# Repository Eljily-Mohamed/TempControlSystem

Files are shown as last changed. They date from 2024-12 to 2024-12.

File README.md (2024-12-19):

# Objectifs du Projet

Notre mission lors de ce projet d'Instrumentation et Puissance des Systèmes (IPS) a été de concevoir un système d'asservissement de température pour une résistance chauffante. L'objectif principal est de mesurer et réguler précisément la température à l'aide d'une thermistance et d'un capteur de courant.

## **Objectifs Détaillés**

À partir du cahier des charges, nous nous sommes répartis les différentes tâches. L'objectif final est de :

- Concevoir un système de mesure complet permettant de relever des données telles que la température et le courant consommé par la résistance.
- Réguler la température en ajustant la puissance appliquée à la résistance chauffante via un MOSFET, en fonction des mesures effectuées.
- La mise en œuvre d’un **capteur de courant ACS712** pour surveiller la puissance consommée par la résistance chauffante.  
- Analyser les résultats obtenus pour les comparer avec les prévisions théoriques issues de l'équation de la chaleur.
- Étudier l'influence de la convection forcée en utilisant un ventilateur pour améliorer la dissipation thermique.

## **Schéma Fonctionnel**

Pour atteindre nos objectifs, nous avons établi un schéma fonctionnel décrivant le fonctionnement global du système. Ce schéma comprend :

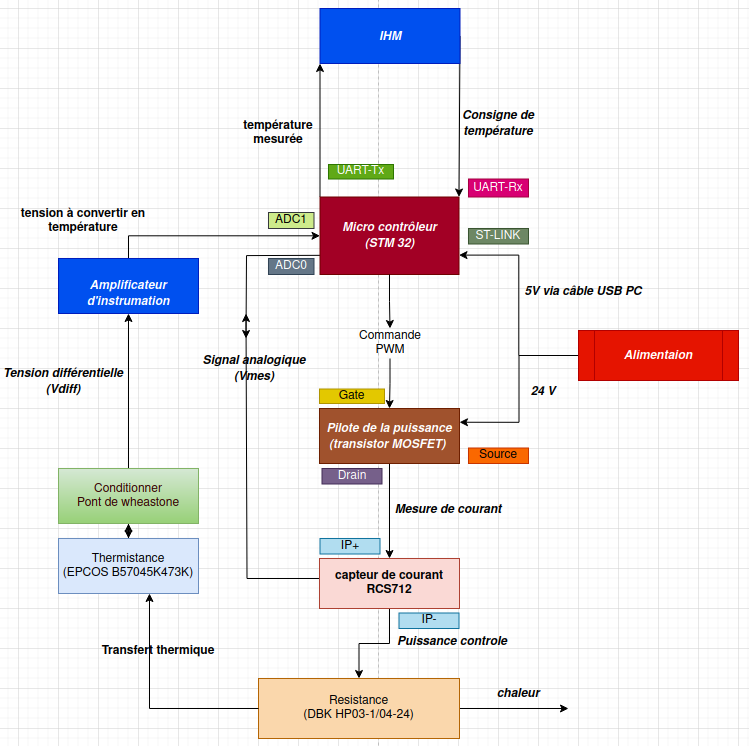
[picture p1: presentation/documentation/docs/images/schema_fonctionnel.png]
Schéma Fonctionnel


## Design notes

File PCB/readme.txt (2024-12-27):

🔧 Modifications nécessaires pour le PCB :

    Le PCB actuel n'est pas le design final. Il manque des connexions importantes pour le fonctionnement correct pour capteur courant.

    Alimentation :
        Ajoutez une alimentation commune pour le +5V nécessaire aux AOP.
        Il y a deux broches importantes : IP+ et IP-. Connectez :
            Le drain du MOSFET à IP+.
            IP- à la résistance chauffante.

    Choix des résistances pour le pont :
        Les valeurs des résistances doivent être proches de la résistance R0 de la thermistance.
        Dans le code C, une fonction calcule la résistance de la thermistance en fonction des résistances R1, R2, et R3, grâce à la loi du pont (vue en cours).
        Le pont est constitué de 4 résistances :
            Thermistance, R1, R2, et R3.

    Résistance pull-down :
        La résistance pull-down connectée au MOSFET doit être placée entre le drain et la gate.
        Vous pouvez souder cette résistance directement sans l'ajouter au PCB.
        Une valeur de 10 kΩ est bonne, mais pas obligatoire. Vous pouvez ajuster selon le besoin.

    Transistor et alimentation :
        Alimentez le transistor avec une tension de 24V.
        Pour le transistor utilisé ici :
            La broche source est au centre.
            Les autres sont drain et gate (voir le PCB).

    Configuration de la gate (PWM) :
        Vous pouvez modifier la broche de la gate pour qu’elle soit connectée à D13.
        Si ce n’est pas le cas, après réception du PCB, vous pouvez réaliser un pontage avec un câble reliant D13 à la broche utilisée.
        Dans le code, j’utilise D13 pour générer un signal PWM.

👉 Si vous avez besoin d’autres précisions ou d’un choix spécifique, faites-moi signe !

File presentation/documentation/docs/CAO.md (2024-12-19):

# Carte Électronique
## **Conception et Tests**

Après avoir testé individuellement chaque composant de la carte, nous avons constaté que les valeurs fournies par la thermistance sont faibles et perturbées.

Pour résoudre ce problème et garantir une précision optimale, nous utilisons un amplificateur différentiel AD623, qui ajuste, amplifie et stabilise le signal avant son envoi vers la carte STM32 pour traitement.

Dans un premier temps, le câblage a été réalisé sur une **plaque Labdec** pour vérifier la fonctionnalité de chaque composant. Une fois les tests validés, nous avons procédé à la **conception assistée par ordinateur (CAO)** du circuit électronique en utilisant un logiciel dédié, ce qui a permis de finaliser la carte PCB présentée en image ci-dessous.

## **Schéma PCB**
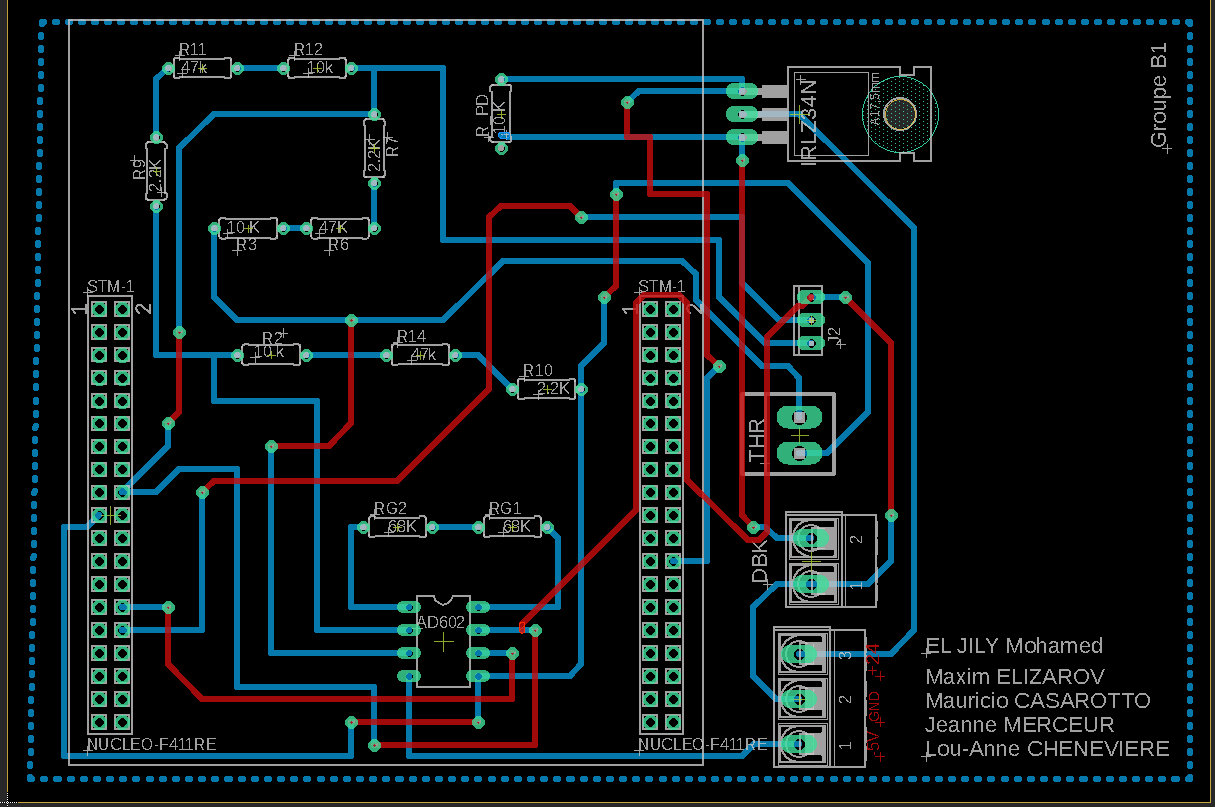
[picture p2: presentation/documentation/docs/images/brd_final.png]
brd final
 

## Description du Circuit

La carte électronique exploite plusieurs composants essentiels pour la réalisation du projet d’asservissement de température :

### 1. **Pont de Wheatstone**  
Le circuit utilise une configuration en **pont de Wheatstone** pour mesurer les faibles variations de résistance de la thermistance. La sortie du pont fournit une tension proportionnelle à la variation de température, exprimée par la relation suivante :  

Vm = (ΔR / R) * Ve

Cependant, la tension obtenue est faible et sensible aux perturbations.

### 2. **Amplification du Signal**  
Afin d'améliorer la précision des mesures et réduire l'impact du bruit observé lors des tests initiaux, nous utilisons un **amplificateur différentiel AD623**. Cet amplificateur permet d’ajuster, stabiliser et amplifier le signal provenant du pont de Wheatstone avant son envoi vers la carte **STM32** pour traitement numérique.

### 3. **Connectivité et Contrôle**  
- **STM32** : La carte STM32 joue un rôle central dans l'acquisition et le traitement des données.  
- **Connectique** : La carte intègre une connectivité facilitant l’interaction avec d’autres composants, tels que le ventilateur pour la convection forcée.

## Réalisation Finale

L’image présentée illustre la carte PCB finale, incluant :  
- Les connexions avec les jauges de déformation et la thermistance,  
- Le pont de Wheatstone pour la mesure des résistances,  
- L’amplificateur **AD623** pour la stabilisation et l’amplification du signal,  
- Les ports de connexion **STM32** pour le traitement numérique et les actions correctives.

Cette carte représente une solution optimisée pour le projet d’asservissement de température, permettant d'obtenir des résultats précis tout en minimisant le bruit et les perturbations.

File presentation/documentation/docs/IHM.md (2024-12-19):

# IHM

L'interface graphique ci-dessous permet de superviser et de contrôler le système de régulation de température basé sur un élément chauffant. Elle offre une vue d'ensemble sur les mesures de température, la puissance appliquée et les paramètres de régulation en temps réel.

## Fonctionnalités principales :

- **Point de Consigne de Température** : Permet de définir la température cible en °C.
- **Mesures affichées** :
  - **Tension (V)** : La tension mesurée.
  - **Duty Cycle (%)** : Le pourcentage du signal PWM utilisé pour contrôler la puissance.
  - **Courant (A)** : Le courant mesuré.
- **Graphiques** :
  - **Température au fil du temps** : Suivi de la température du système.
  - **Variation de puissance** : Suivi de la puissance envoyée à l'élément chauffant.

## Contrôle de l'acquisition :
Un bouton **"Démarrer l'acquisition"** permet de commencer la collecte et l'affichage des données en temps réel.

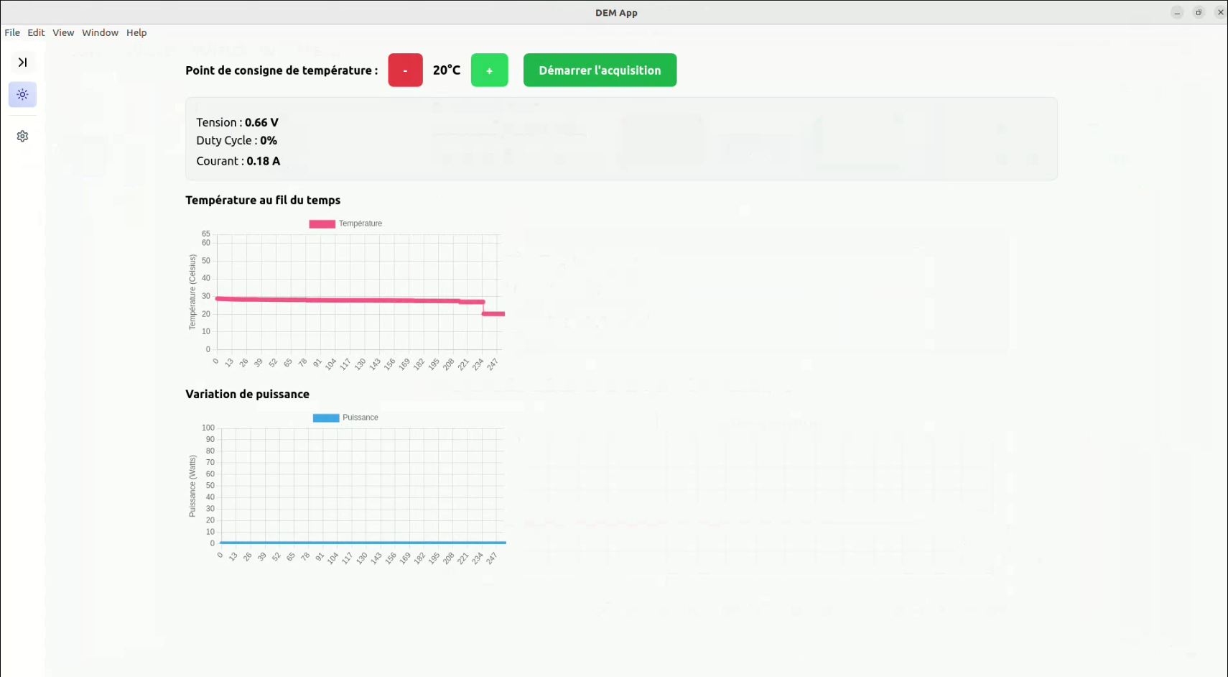
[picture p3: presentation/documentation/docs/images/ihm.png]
IHM


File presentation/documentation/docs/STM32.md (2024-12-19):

# STM32

Avant de commencer les tâches spécifiques à notre projet, il est essentiel de configurer les broches, récupérer les tensions via l'ADC et utiliser les minuteries. Ces bases sont indispensables pour les tâches à venir dans le cadre du module IPS.

## Tâche 1 : Programmation d'une tâche périodique (1 seconde)

Nous devons configurer des minuteries pour créer des tâches périodiques sur la carte STM32.

**Objectifs :**
- **Configurer un timer** pour générer des interruptions périodiques.
- **Vérifier les périodes** avec un oscilloscope.

**Pourquoi c'est important pour le projet :**  
Cela permettra de gérer les actions périodiques et synchroniser le traitement des données.

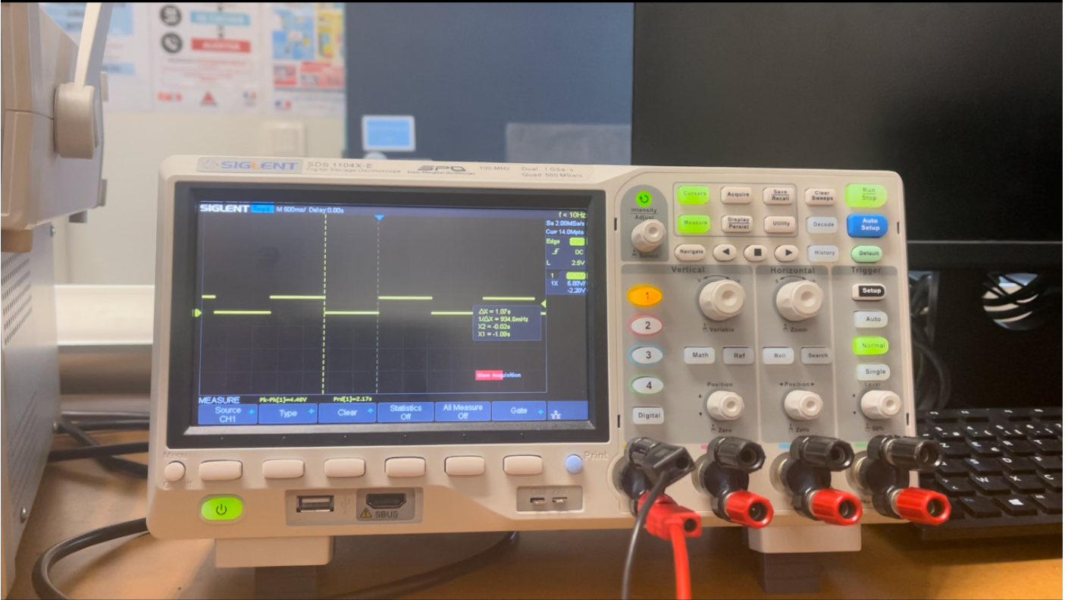
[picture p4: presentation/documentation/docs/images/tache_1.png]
Tâche 1


## Tâche 2 : Acquisition d'une donnée analogique via l'ADC

Nous utiliserons l'ADC pour lire une valeur analogique, puis la convertir en une tension numérique.

**Objectifs :**
- **Configurer l'ADC** pour lire la donnée analogique.
- **Convertir et afficher** la tension correspondante.

**Pourquoi c'est important pour le projet :**  
Cela permet d'acquérir des données analogiques provenant des capteurs.

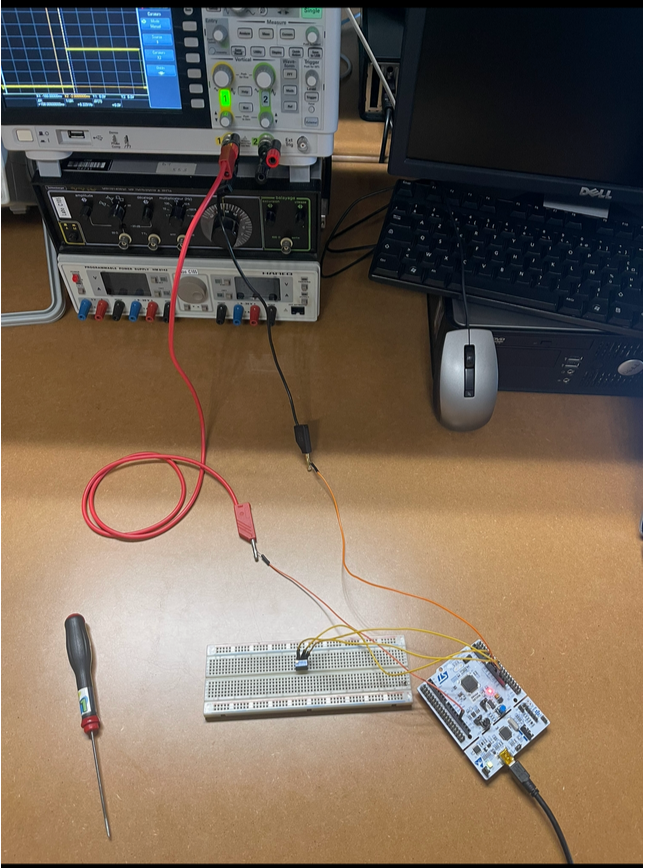
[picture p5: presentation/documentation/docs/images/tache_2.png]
Tâche 2


## Tâche 3 : Envoi des données vers le PC via UART (USB)

Nous enverrons les données acquises de la STM32 vers un PC via UART.

**Objectifs :**
- **Configurer UART** pour envoyer les données vers le PC.
- **Vérifier la transmission** avec un terminal comme PuTTY.

**Pourquoi c'est important pour le projet :**  
Cela permet de visualiser et analyser les données collectées.

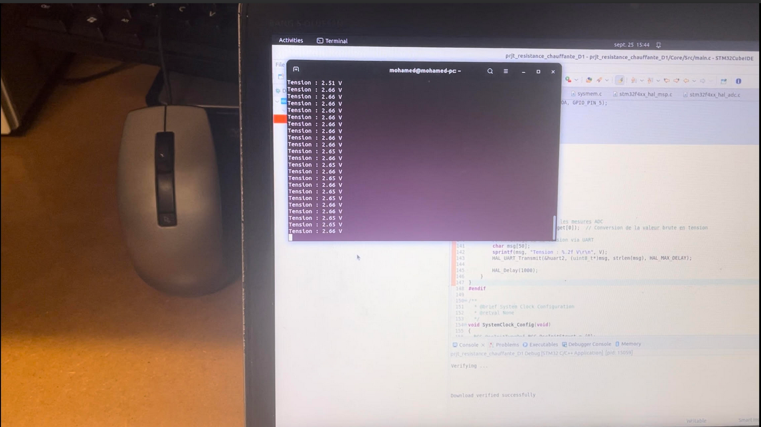
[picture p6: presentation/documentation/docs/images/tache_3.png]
Tâche 3


# Processus Expérimental du Projet STM32

Une fois les tâches de configuration de la carte STM32 terminées, nous démarrons le processus expérimental global du projet.

## 1. Câblage du Système Global

Après avoir finalisé les tâches de configuration sur la carte STM32, nous passons à l'étape suivante qui consiste à câbler l'ensemble du système.

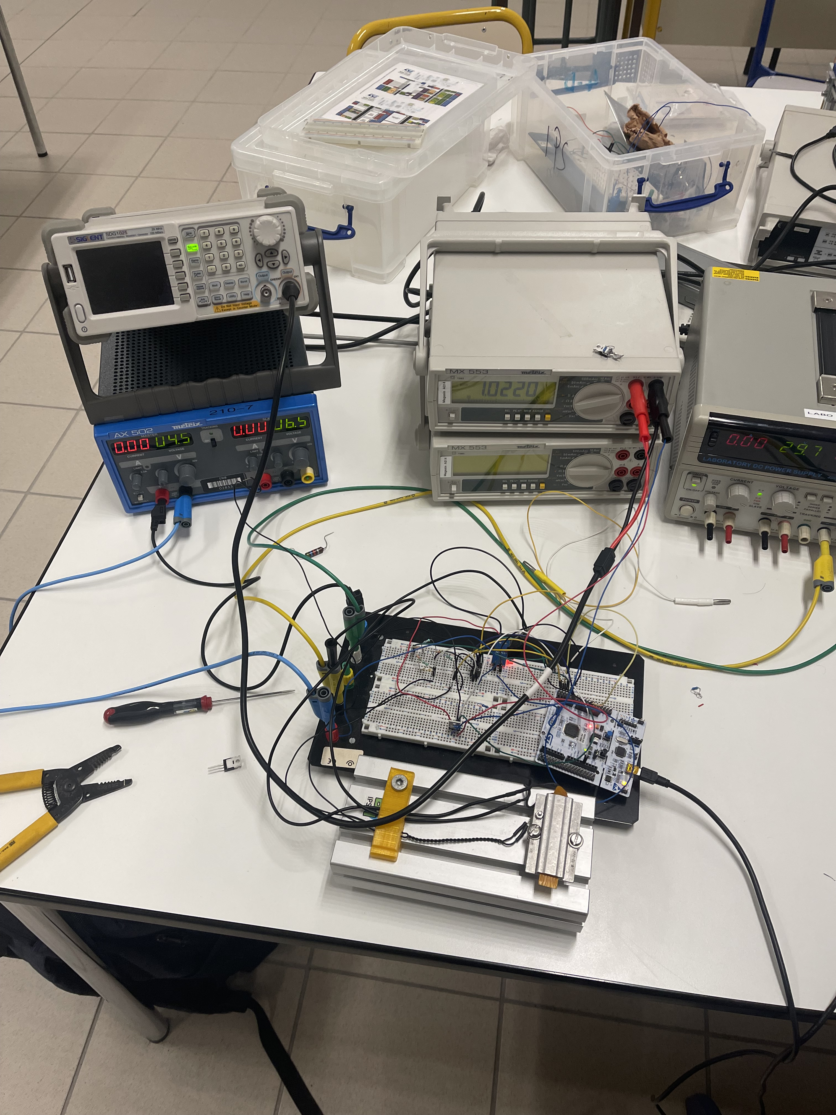
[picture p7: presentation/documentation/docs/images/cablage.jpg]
Câblage du système


### Étapes :
- **Câblage de la broche PA0** : Cette broche est utilisée pour récupérer la tension en sortie de l'AOP.
- **Vérification du signal** : À l'aide d'un multimètre, nous vérifions que la tension récupérée sur PA0 correspond à la tension attendue sortie de l'AOP.

## 2. Ajout d'une Broche pour la Récupération de la Sortie du Capteur de Courant

Une fois le câblage vérifié, nous ajoutons une autre broche, **PA1**, pour récupérer la sortie du capteur de courant. Cette étape est cruciale pour l'acquisition des données nécessaires à l'asservissement du système.

- **PA1** : Récupère la sortie du capteur de courant.

## 3. Mise en Place de la Tâche Périodique pour la Récupération des Données

Pour récupérer les données de manière régulière, nous configurons un timer afin de lancer la mesure périodiquement.

- **Timer périodique** : Permet de récupérer les mesures des capteurs à intervalles réguliers pour le traitement ultérieur.

## 4. Traitement des Données pour l'Asservissement

Une fois les données récupérées, nous passons à leur traitement pour calculer la température et déterminer le courant, afin de procéder à l'asservissement du système.

- **Calcul de la température** : À partir des données récupérées, la température est calculée.
- **Calcul du courant** : La mesure du courant est utilisée pour ajuster l'asservissement.

## 5. Contrôle du Signal PWM

Le traitement des données permet de déterminer le **duty cycle** du signal PWM, qui sera ensuite envoyé pour réguler la température et le courant dans l'élément chauffant.

- **PWM** : En fonction des calculs, un signal PWM est généré pour contrôler l'élément chauffant en fonction de la température et du courant mesurés.

## 6. Phase 3 : Récupération de la Consigne via USART

Dans cette phase, nous ajoutons la capacité de recevoir une consigne de température via la communication USART. Cette consigne permettra d'ajuster le comportement du système en fonction des demandes externes.

### Étapes :
- **Récupération de la consigne via USART** : Le système reçoit la consigne de température via un terminal ou une autre source, en utilisant la communication USART.
- **Modification de la consigne dans l'asservissement** : La consigne reçue via USART est utilisée pour ajuster la température cible, et donc le calcul du PWM.

## 7. Ajustement du PWM en fonction de la Consigne

Une fois la consigne reçue, le système adapte le calcul du signal PWM pour réguler la puissance envoyée à l'élément chauffant et atteindre la température cible spécifiée par la consigne.

- **Contrôle dynamique de la température** : La consigne via USART permet un contrôle dynamique et à distance de la température de l'élément chauffant, en ajustant le signal PWM en conséquence.

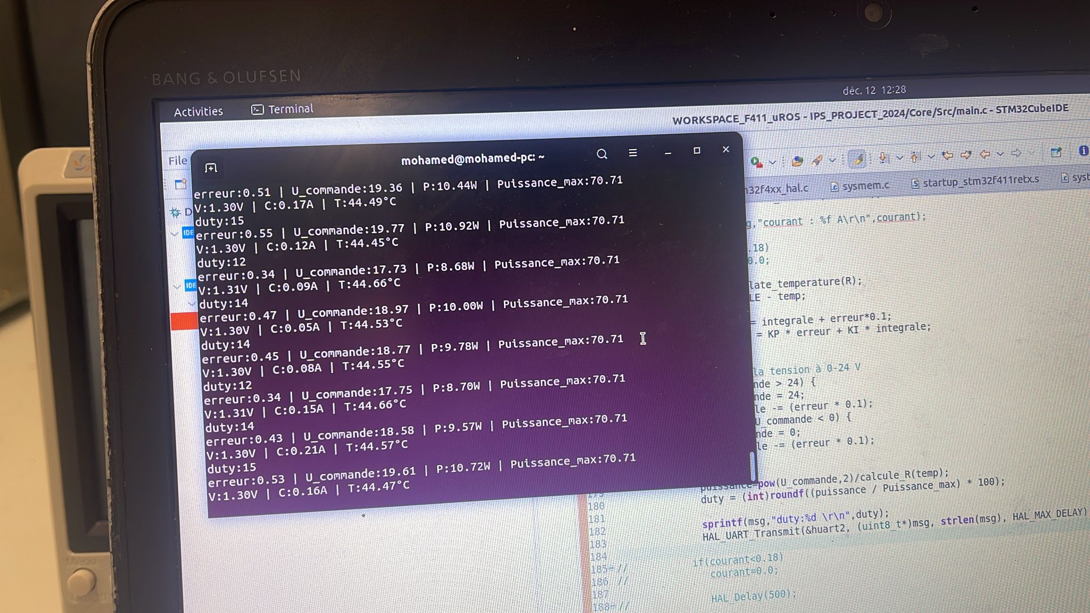
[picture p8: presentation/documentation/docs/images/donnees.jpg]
Données récupérées


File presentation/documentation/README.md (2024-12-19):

# Documentation du Projet avec MkDocs

Ce projet utilise **MkDocs** pour créer et héberger une documentation structurée.

## Prérequis

Assurez-vous d'avoir installé **Python** (>=3.6) et **pip** (le gestionnaire de paquets Python).

2. Installez les dépendances nécessaires :

   ```bash
   pip install -r requirements.txt
   ```

---

## Lancer la documentation en local

Pour visualiser votre documentation en local, exécutez la commande suivante :

```bash
mkdocs serve
```

Cela démarre un serveur local. Ouvrez votre navigateur et accédez à :

```
http://127.0.0.1:8000/
```

Les modifications apportées aux fichiers seront automatiquement rechargées.

## Lien vers notre site web
https://docs-ips.onrender.com/

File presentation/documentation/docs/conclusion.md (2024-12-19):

# Conclusion

## Comparaison expérimentale et finale

Nous avons étudié le chauffage et le refroidissement du système, d'abord de manière théorique, puis expérimentalement, afin de calibrer notre code STM32 et de tester le système final.
Nous avons constaté que les conditions extérieures, telles que la température ambiante, influencent significativement les mesures, entraînant des variations d’un jour à l’autre.
Cependant, en analysant le système dans différentes conditions, nous avons développé une solution plus fiable et modulable.

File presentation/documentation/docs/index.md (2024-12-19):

# Page d'accueil du projet

Bienvenue sur la documentation de notre projet, réalisé par des étudiants de l'École Nationale d'Ingénieurs de Brest (ENIB). Ce projet a pour objectif de concevoir un système d'instrumentation permettant de mesurer et de réguler précisément la température d'une résistance chauffante à l'aide d'une thermistance et d'un capteur de courant.

## **Régulation de Température d’une Résistance Chauffante par Thermistance**

Dans ce projet, nous avons développé un système qui repose sur :  
- L’utilisation d’une **résistance chauffante** et d’une **thermistance** pour contrôler et mesurer la température en temps réel.  

## **Composants clés utilisés**

### **Résistance chauffante : DBK HP03-1/04-24**  

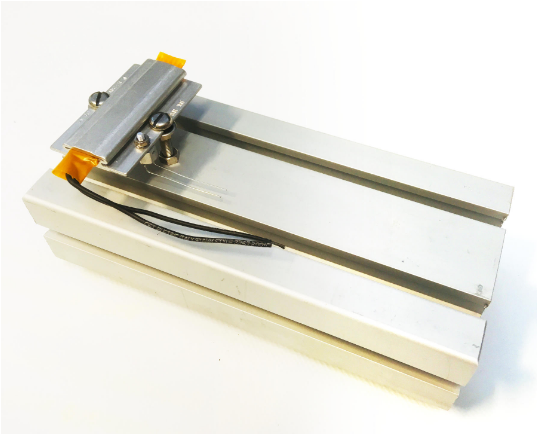
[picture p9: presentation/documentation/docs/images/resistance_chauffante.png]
Résistance chauffante
  

La **DBK HP03-1/04-24** est une résistance chauffante compacte et fiable, idéale pour des expériences de contrôle de température nécessitant une précision élevée.  

### **Thermistance : EPCOS B57045K473K**  

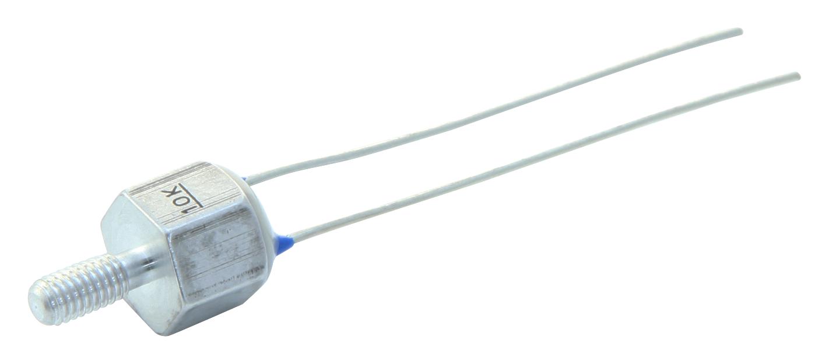
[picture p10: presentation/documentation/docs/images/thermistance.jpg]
Thermistance
  

La **thermistance EPCOS B57045K473K** offre une sensibilité accrue pour mesurer avec précision les variations de température. Elle est idéale pour un système d'asservissement nécessitant une mesure en temps réel.  

### **Capteur de courant : ACS712**  

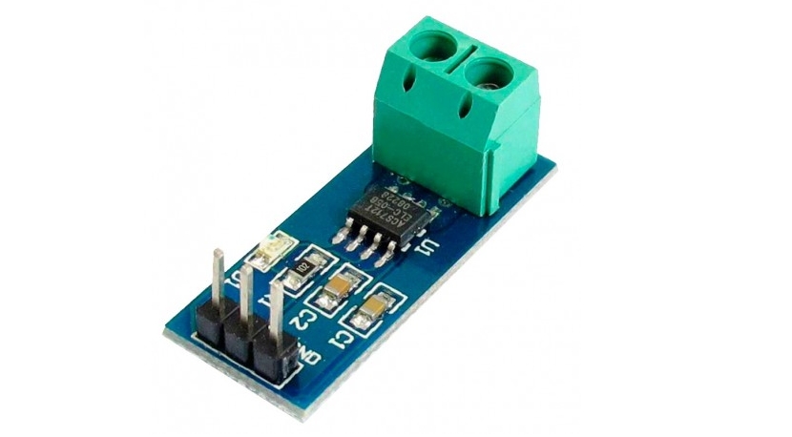
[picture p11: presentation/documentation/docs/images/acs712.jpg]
Capteur de courant ACS712
  

Le **capteur de courant ACS712** permet de mesurer avec précision le courant consommé par la résistance chauffante. Ces mesures sont essentielles pour analyser la relation entre la puissance dissipée et la variation de température du système.

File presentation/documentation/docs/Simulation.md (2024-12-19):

# Simulation théorique

## **Introduction**  
L'étude repose sur **l'équation de la chaleur** avec les paramètres :  
**m** : masse | **Cp** : capacité thermique | **hc** : convection | **S** : surface | **T(t)** : température | **P(t)** : puissance | **Ta** : température ambiante.

La température est calculée via l'équation NTC :  
Equation Chaleur

Des tests de **chauffage** et de **refroidissement** sont effectués en mesurant la résistance de la thermistance à chaque instant pour en calculer la température avec l'équation suivante :  
Equation Refroidissement  
Pendant le chauffage, V = 12 V a été utilisé.

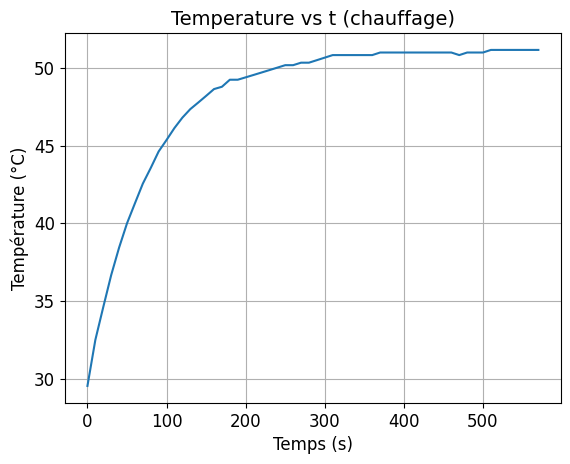
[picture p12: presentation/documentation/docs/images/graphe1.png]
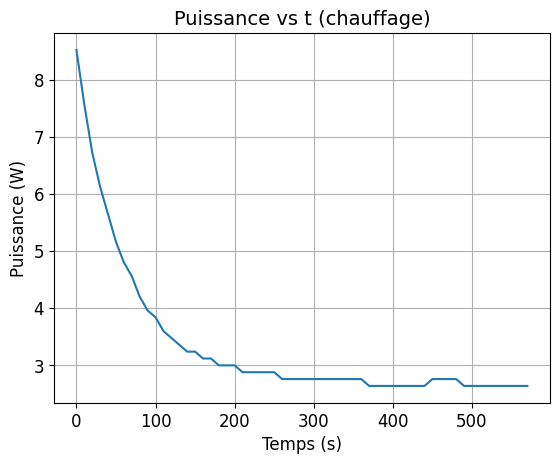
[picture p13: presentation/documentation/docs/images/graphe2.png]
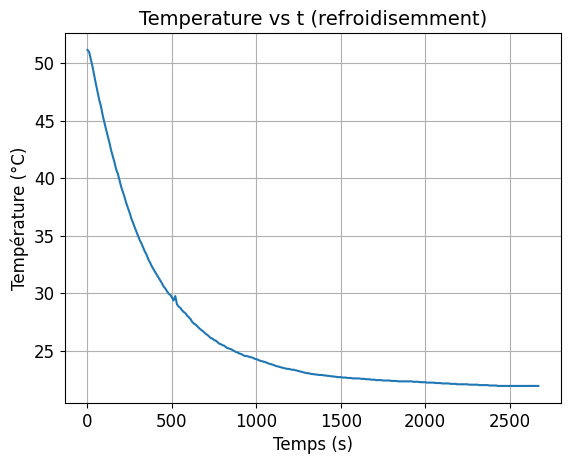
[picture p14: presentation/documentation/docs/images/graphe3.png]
Graphique 3
|  |  |  |
|---|---|---|
| Graphique 1 | Graphique 2 | Graphique 3 |

## **Estimation des paramètres**  
Nous avons utilisé l'équation de refroidissement, avec l'équation différentielle linéaire à coefficients constants, pour calculer les paramètres **m.Cp** et **hc.S**. Nous les regroupons en **a = m.Cp** et **b = hc.S** pour simplifier l'analyse.

L’équation simplifiée est :  
Equation simplifiée  
Sa solution est :  
Equation solution

Le facteur **a/b** représente la constante de temps **τ**, et avec **T(τ) = 0,63 Tfin**, nous obtenons **τ = 533.47s**.  

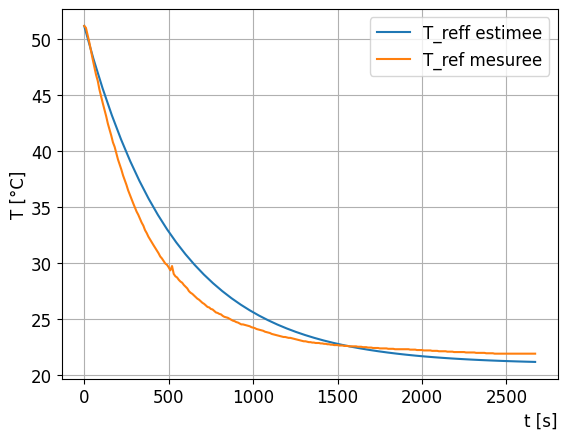
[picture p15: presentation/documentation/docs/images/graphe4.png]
Puissance


Pendant le chauffage, la température tend vers 50°C, donc **δT/δt = 0**, et nous trouvons que **a = 46.67Ws/K**. Cette équation permet de modéliser la variation de température pour une puissance d'entrée fixe de 14 W et la variation de la résistance en fonction de la température.

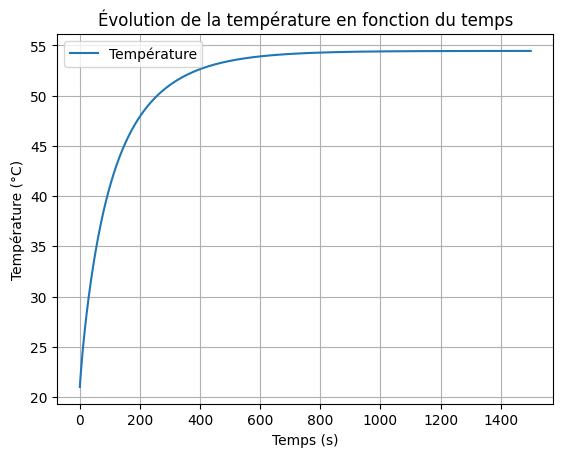
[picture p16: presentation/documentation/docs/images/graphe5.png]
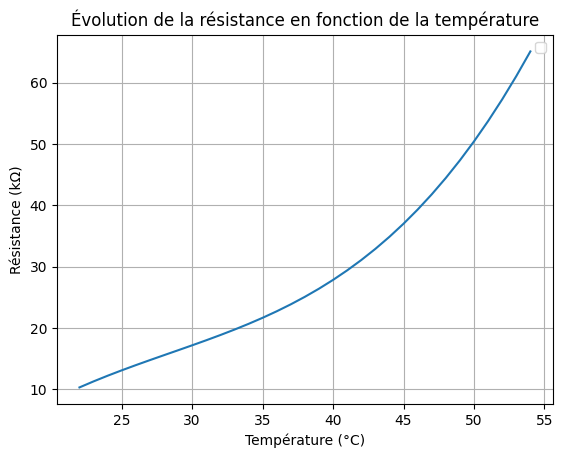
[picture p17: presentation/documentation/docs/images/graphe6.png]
|  |  |
|---|---|
| Graphique 1 | Graphique 2 |

## **Contrôle PID**  
Une fois les paramètres obtenus, les valeurs de gain ont commencé à être testées pour effectuer un contrôle PID, obtenant finalement KP= 8.1785, KI = 0.14733 et KD = 0 (Nous avons confirmé l'obtention d'une bonne réponse sans contrôle dérivé). Le contrôle a été modélisé à partir de ces valeurs pour différentes températures de consigne.

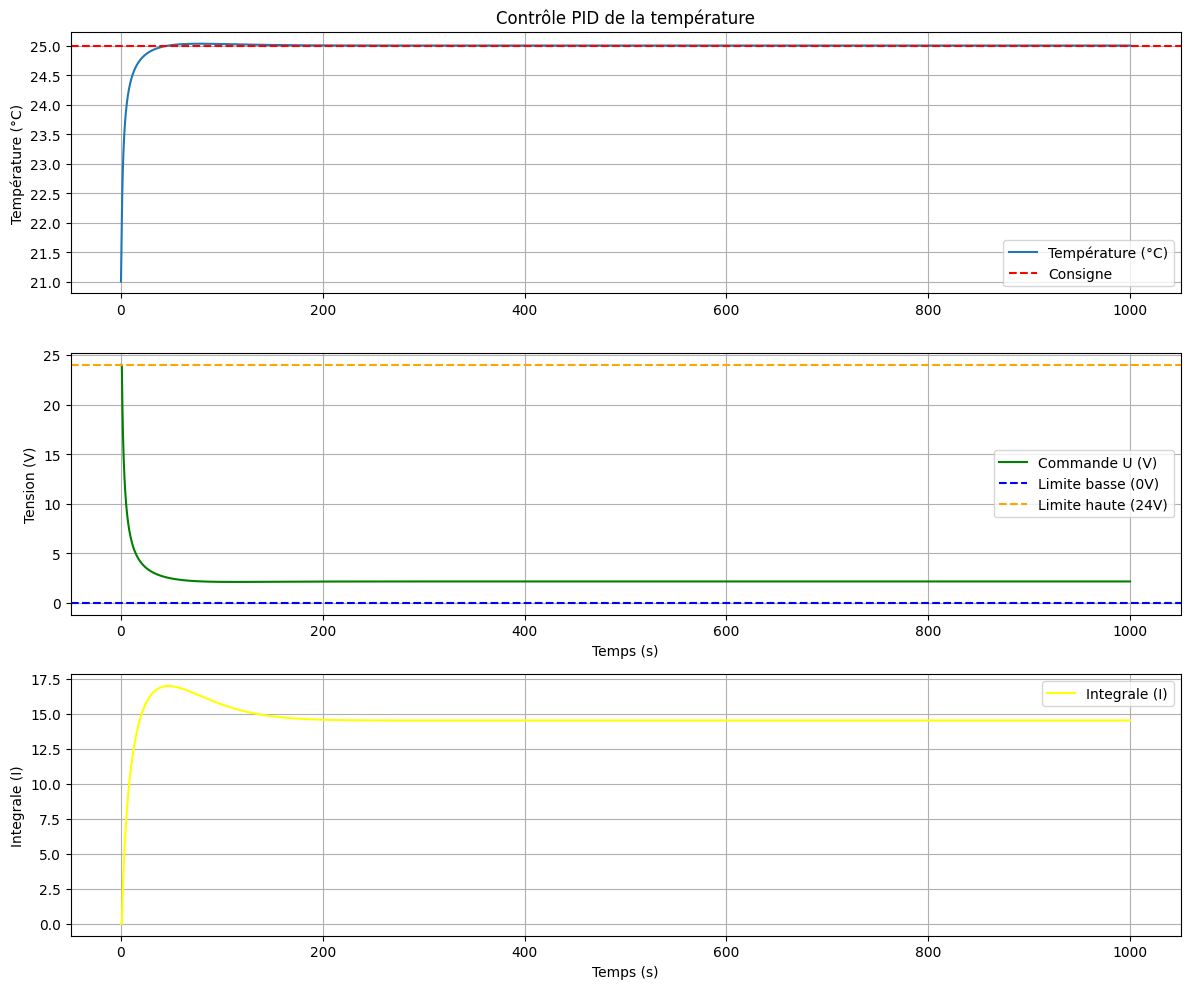
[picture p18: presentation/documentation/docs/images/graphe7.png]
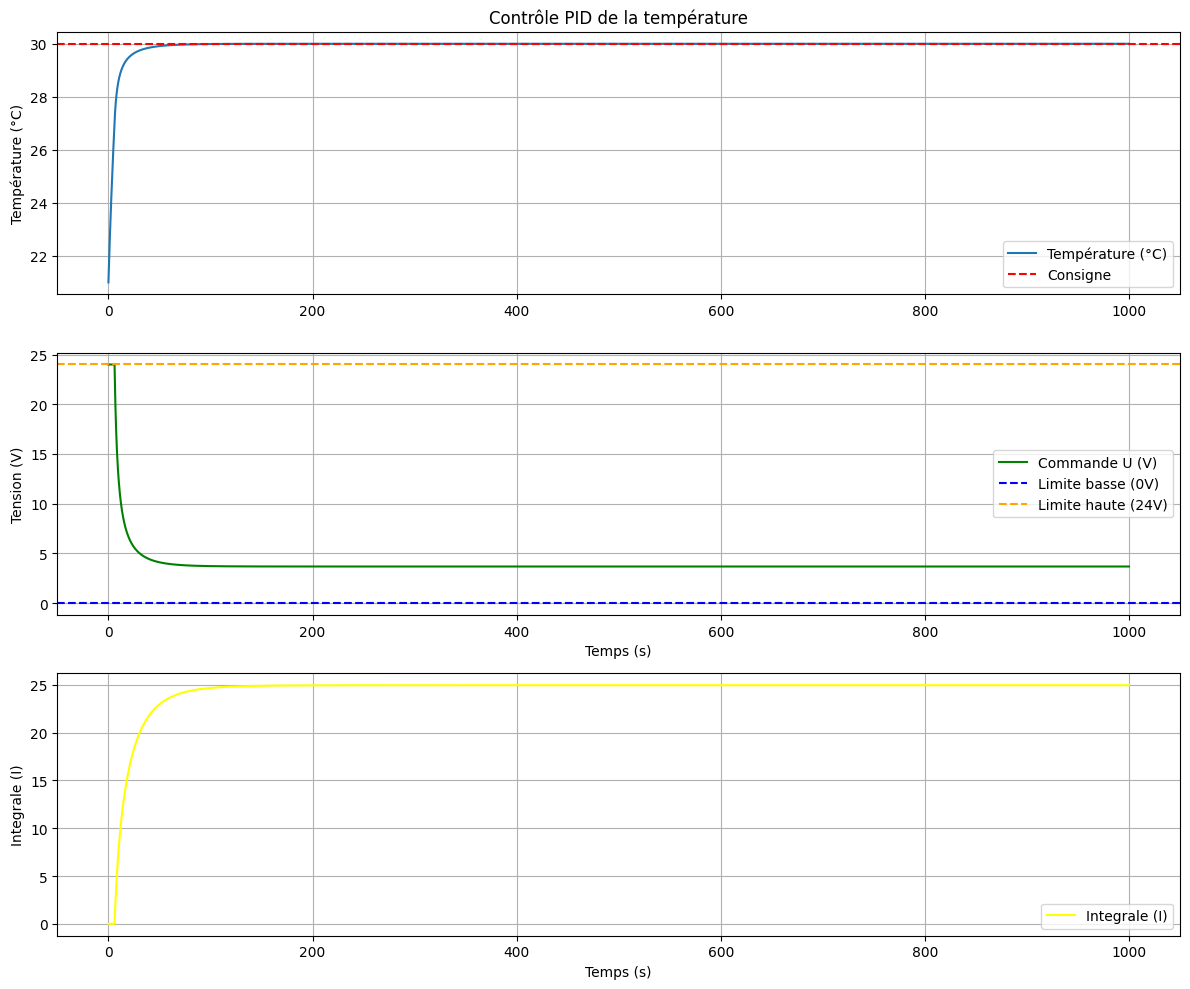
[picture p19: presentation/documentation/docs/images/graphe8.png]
|  |  |
|---|---|
| Graphique 1 | Graphique 2 |

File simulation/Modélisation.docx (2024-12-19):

Intro

Notre système est basé sur l'équation de la chaleur :

m.C_p .(dT(t))/(dt)+ h_c .S.T(t)=P(t)+ h_c .S.T_a (t)

- m : masse de la plaque chauffante
- Cp : capacité thermique spécifique
- hc : coefficient de transfert de chaleur par convection
- S : surface de confinement des pertes de chaleur
- T(t) : température en fonction du temps
- P(t) : puissance d'entrée en fonction du temps
- Ta : température ambiante

Ensuite, nous effectuons des tests de chauffage et de refroidissement, en mesurant à chaque instant la résistance de la thermistance pour en calculer la température grâce à l'équation T(r)= 1/(1/(T_0)+1/β.ln(r/(R_0))) , étant β constante bêta utilisée dans les équations de thermistance NTC, T0 et R0 valeurs de références (Pendant le chauffage, V = 12 V a été utilisé)


Estimation des paramètres

Nous avons utilisé l'équation de refroidissement pour calculer les paramètres, car nous travaillons ainsi avec une équation différentielle linéaire à coefficients constants car il n'y a pas de terme de puissance. Nous regroupons également les coefficients inconnus, m.Cp et hc.S, pour avoir deux inconnues, a = m.Cp et b = hc.S, au lieu de 4. L’équation résultante est donc a.(dT(t))/(dt)+ b.T(t)=b.T_a (t) , et sa solution est T(t)=(T_(max) -T_a ).e^(-(b.t)/a) +T_a , étant Tmax la température maximale atteinte pendant le chauffage.

Le facteur a/b est la constante de temps τ, et en développant l'expression précédente on arrive à τ= t/(log⁡((T_(max) -T_a)/(T-T_a)))

Sachant que T(τ) = 0,63.Tfin et en observant les valeurs de la courbe de refroidissement, τ = 533.47s a été déterminé


Lors du chauffage, la température tend vers 50°C, donc δT/δt= 0, alors a.δT/δt +b.(T-Ta)=Pe, en prenant la limite δT → 0, on obtient b=(P_e)/(T-T_a) = 0.0875W/K et on peut calculer a = τ*b = 46.67Ws/K.

Nous utilisons cette équation pour modéliser la variation de température pour une puissance d'entrée fixe de 14 W, ainsi que la variation de la résistance de la plaque en fonction de la température.


Une fois les paramètres obtenus, les valeurs de gain ont commencé à être testées pour effectuer un contrôle PID, obtenant finalement KP= 8.1785, KI = 0.14733 et KD = 0 (Nous avons confirmé l'obtention d'une bonne réponse sans contrôle dérivé). Le contrôle a été modélisé à partir de ces valeurs pour différentes températures de consigne.

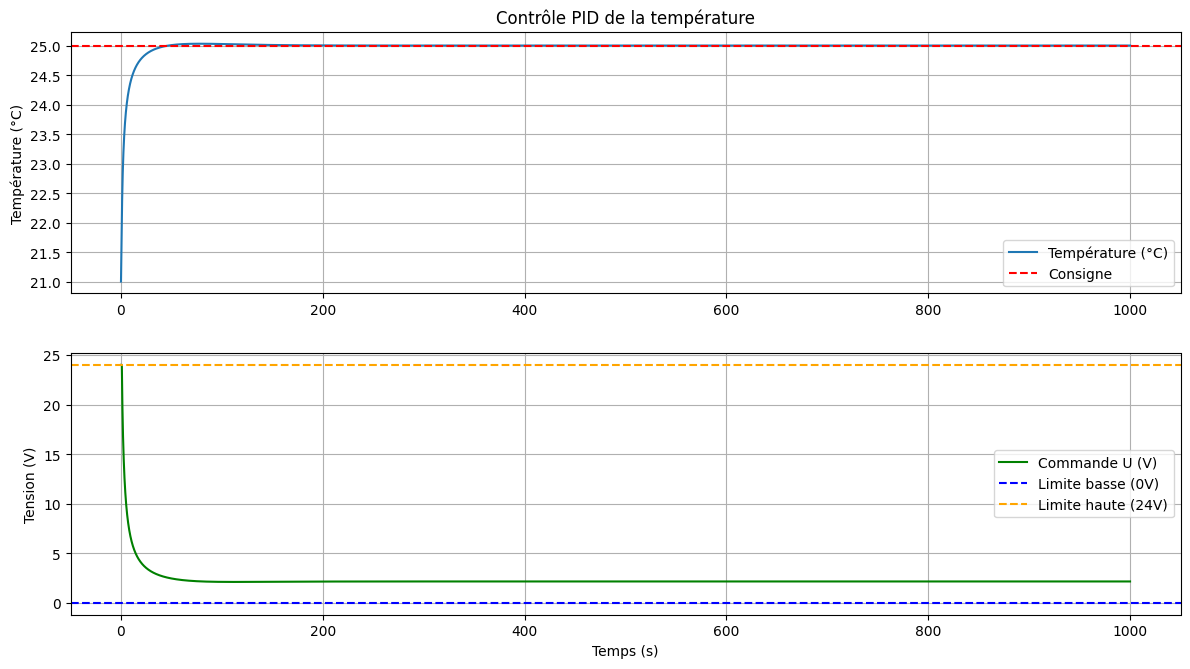
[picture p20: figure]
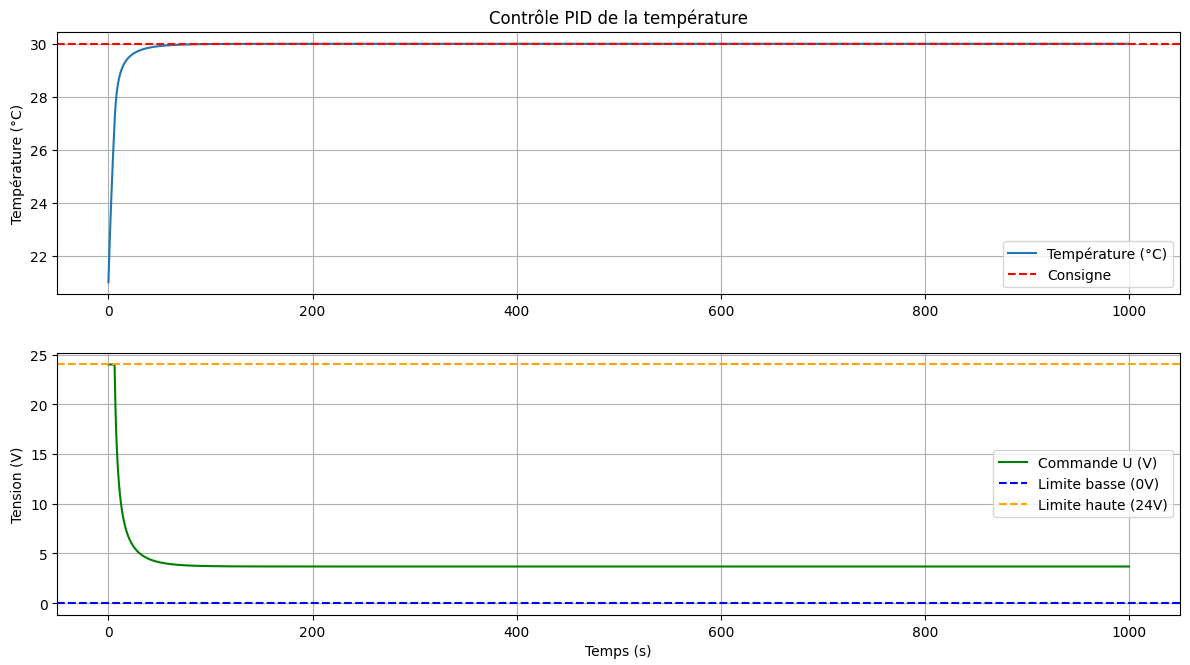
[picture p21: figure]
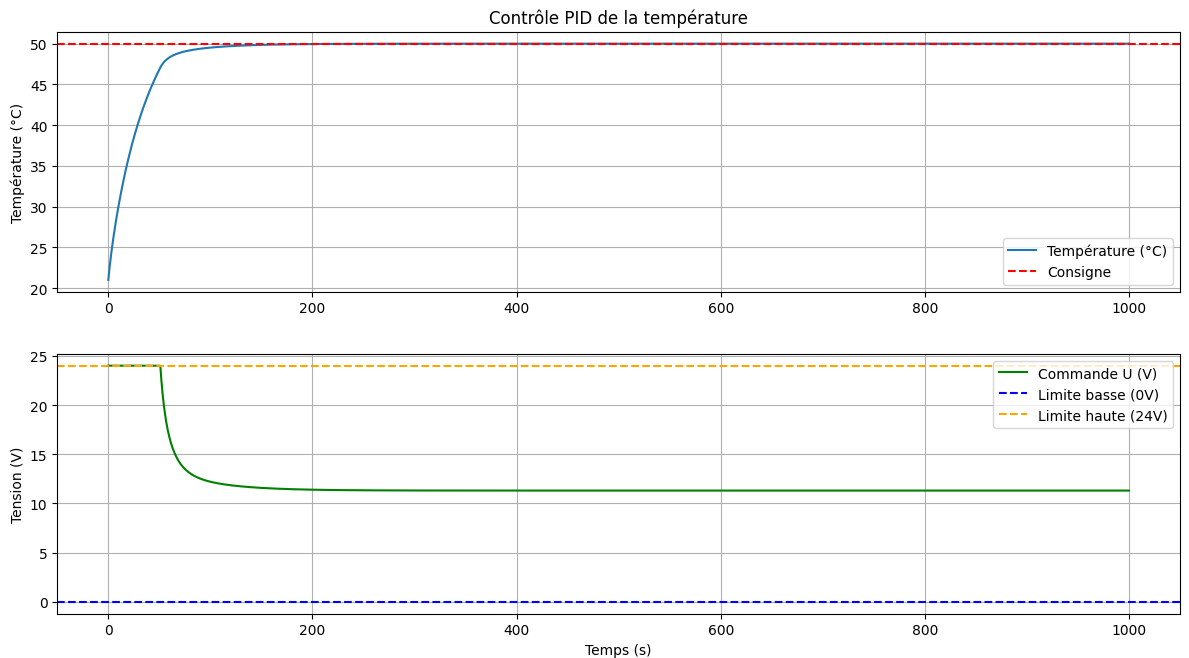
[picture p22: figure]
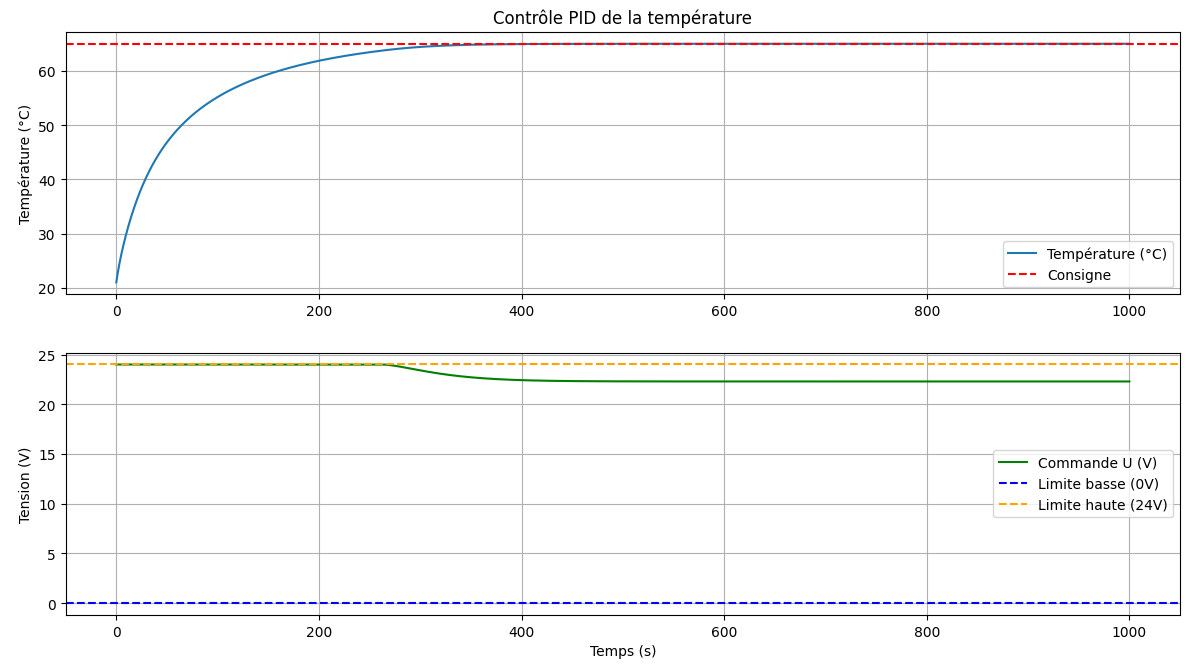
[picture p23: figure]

Nous vérifions que la température maximale réalisable avec la puissance utilisée est

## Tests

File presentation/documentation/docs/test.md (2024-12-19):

# Résultats et Analyse

Voici une démo de notre projet. La vidéo montre deux périodes : la période de refroidissement et la période de chauffage.

---

### Vidéo de démonstration

[Télécharger la vidéo ici](/videos/demo.mp4)

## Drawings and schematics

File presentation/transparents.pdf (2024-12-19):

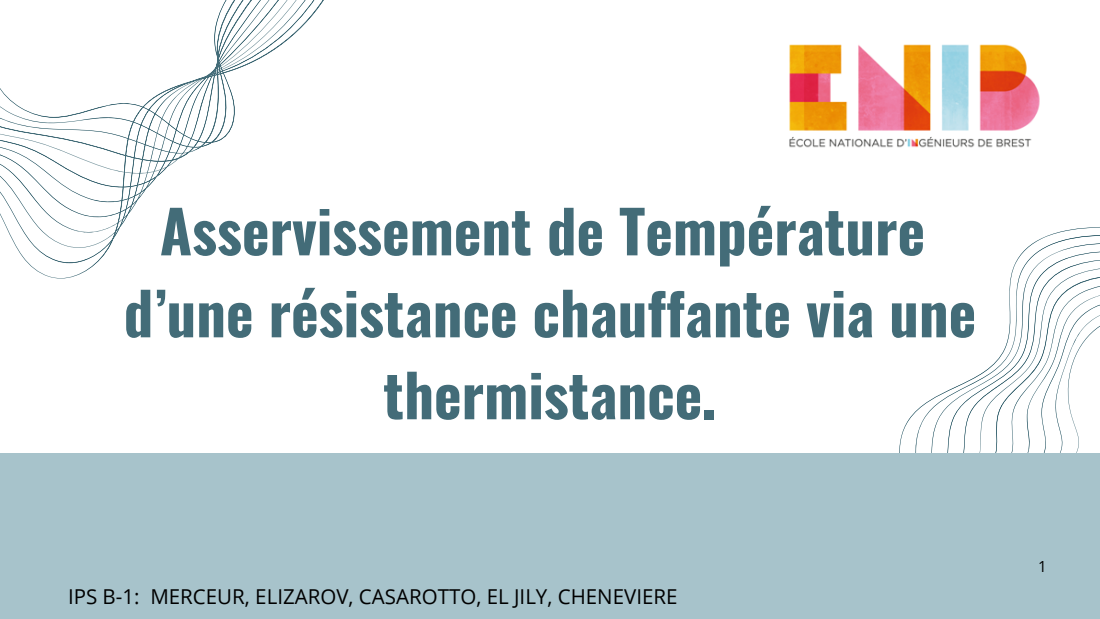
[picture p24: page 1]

Asservissement de Température
d’une résistance chauffante via une
thermistance.

IPS B-1: MERCEUR, ELIZAROV, CASAROTTO, EL JILY, CHENEVIERE

### CONTENT

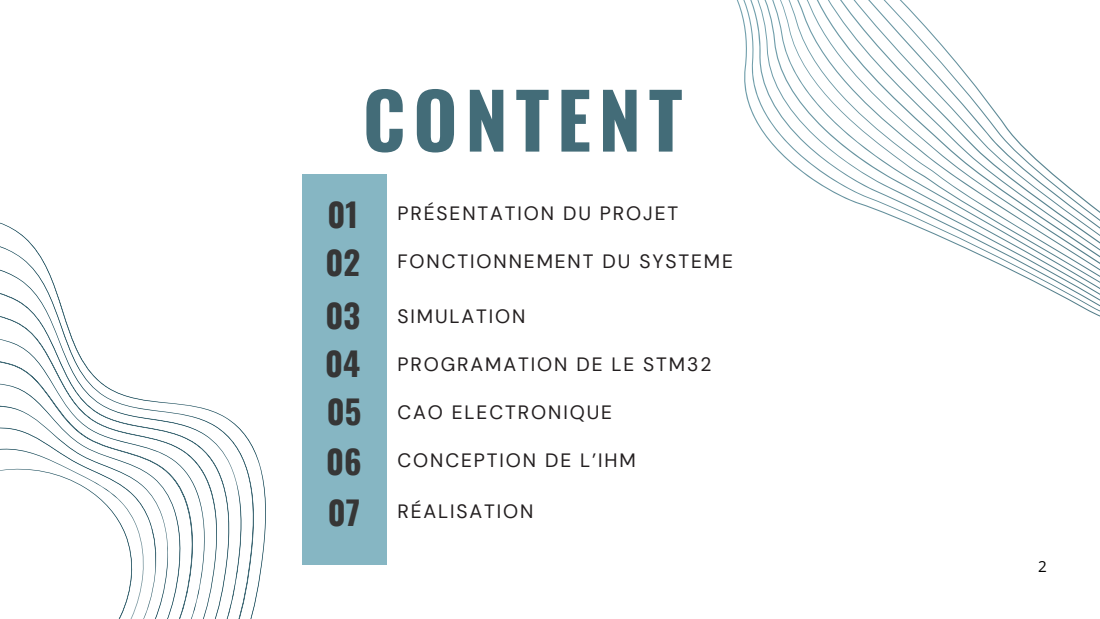
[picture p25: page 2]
PRÉSENTATION DU PROJET; SIMULATION; CAO ELECTRONIQUE; RÉALISATION

FONCTIONNEMENT DU SYSTEME

PROGRAMATION DE LE STM32

CONCEPTION DE L’IHM

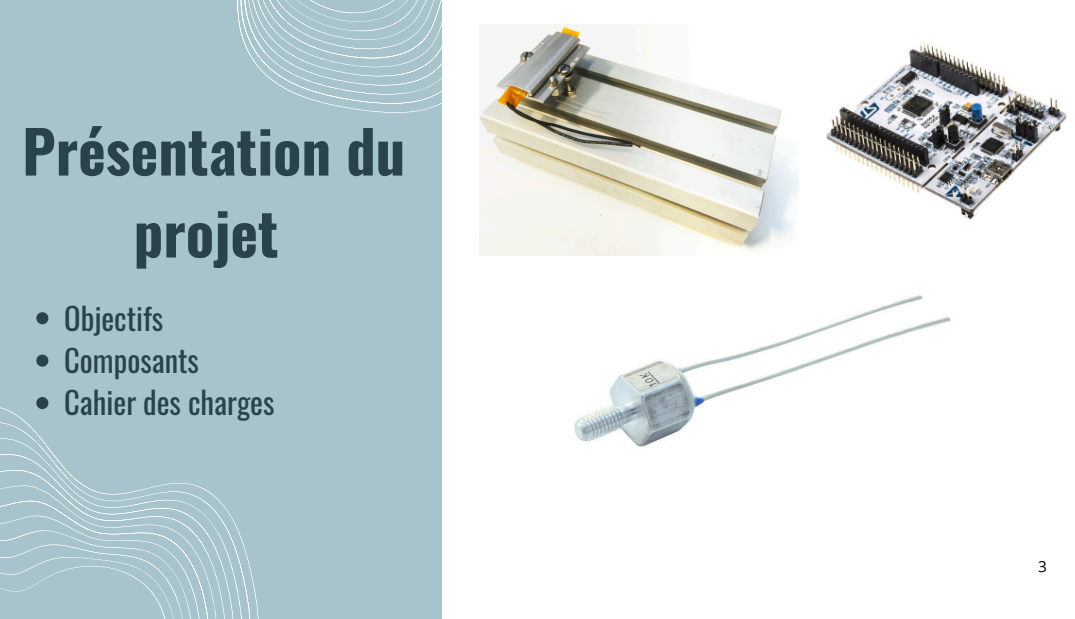
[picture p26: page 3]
tif; hie

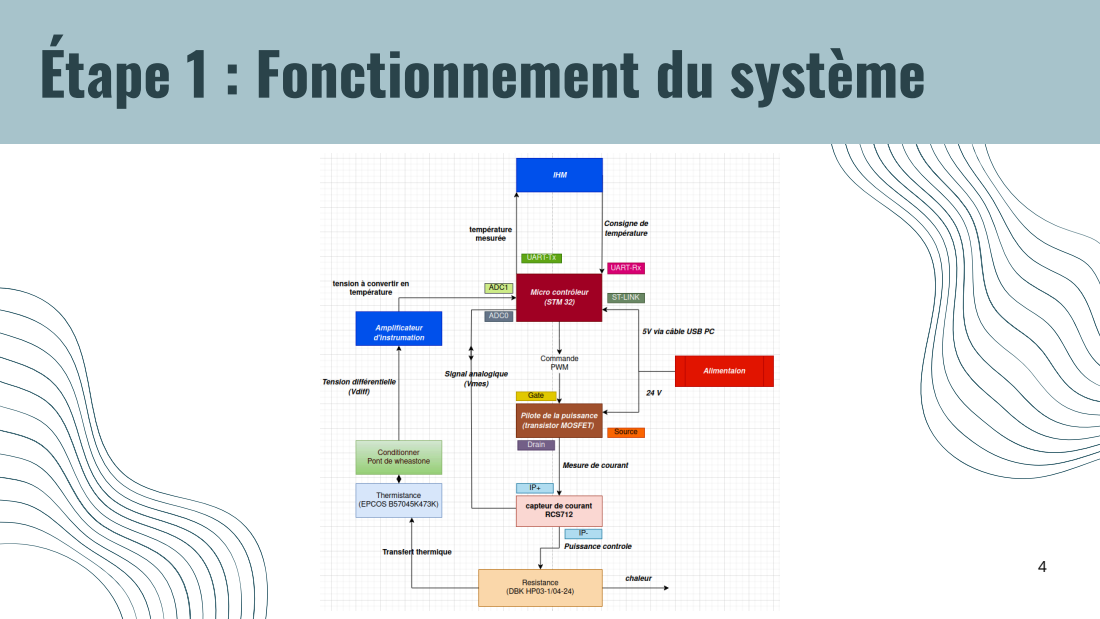
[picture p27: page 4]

Étape 1 : Fonctionnement du système

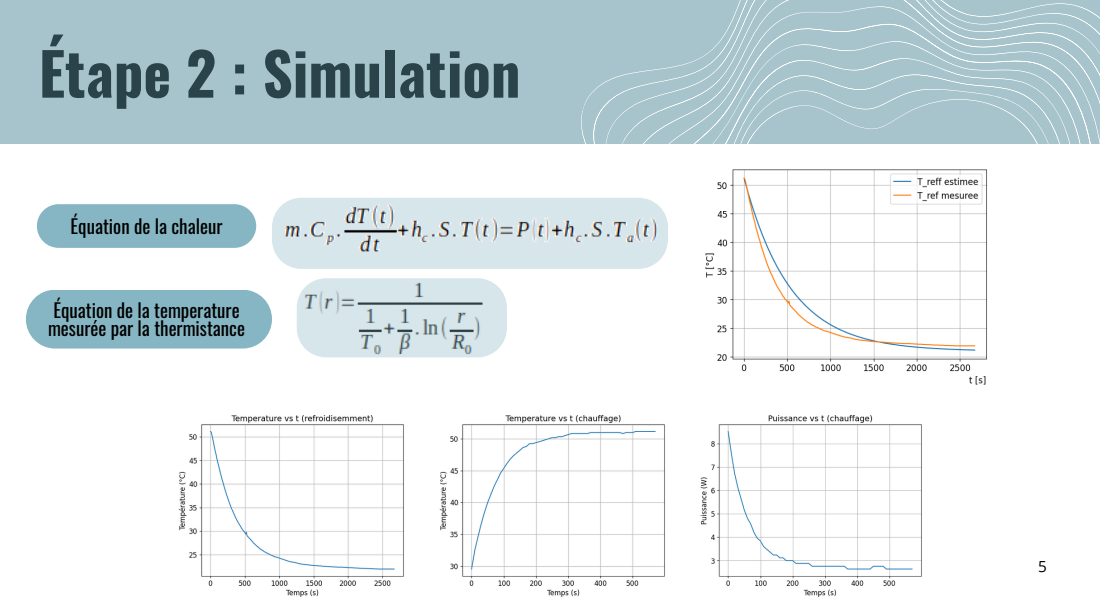
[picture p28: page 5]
Étape 2 : Simulation

Équation de la chaleur

Équation de la temperature
mesurée par la thermistance

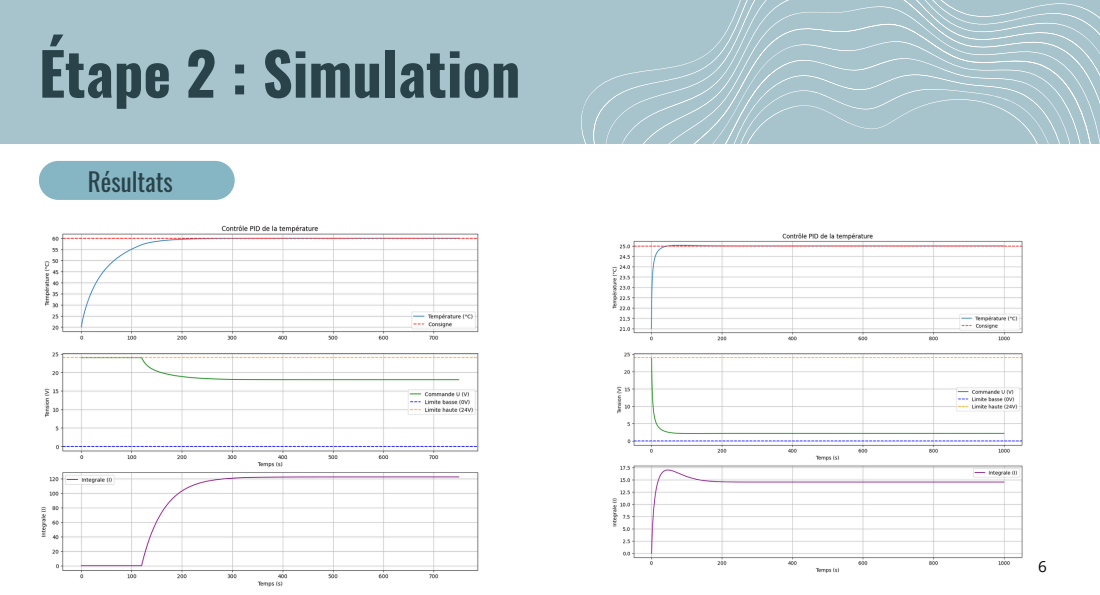
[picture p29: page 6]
Étape 2 : Simulation; Résultats

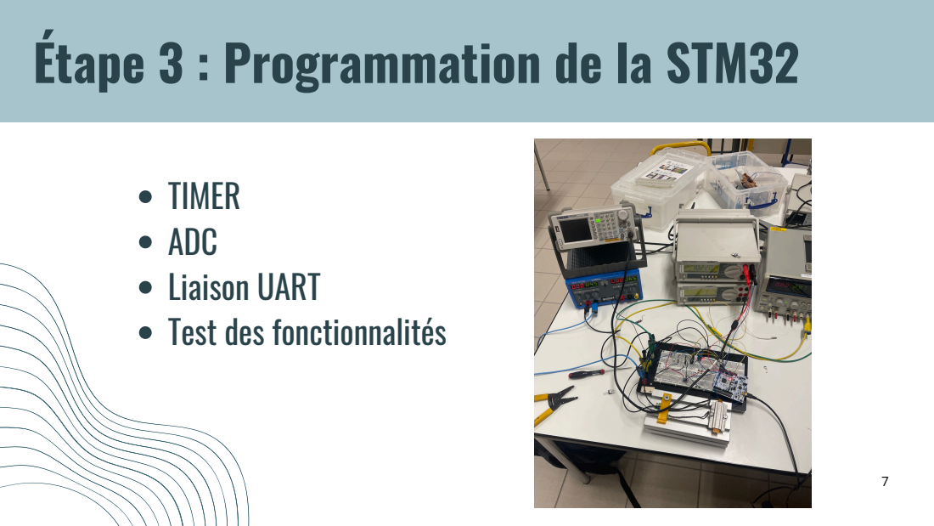
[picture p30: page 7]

Étape 3 : Programmation de la STM32

TIMER
ADC
Liaison UART
Test des fonctionnalités

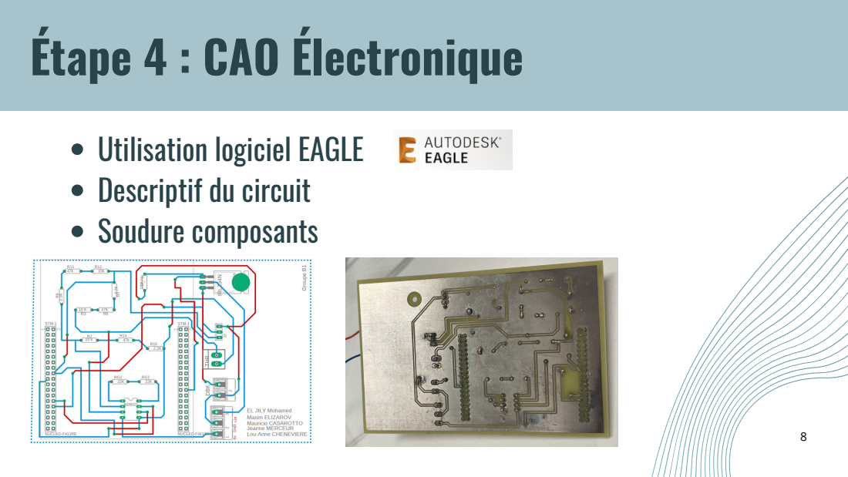
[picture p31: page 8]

Étape 4 : CAO Électronique

Utilisation logiciel EAGLE
Descriptif du circuit
Soudure composants

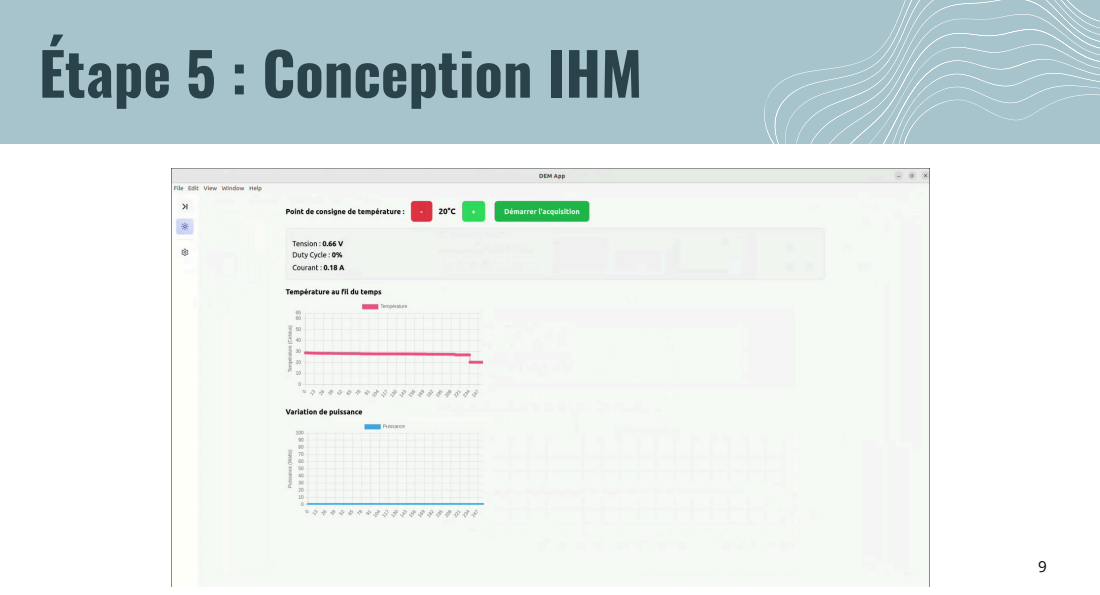
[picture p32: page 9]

Étape 5 : Conception IHM

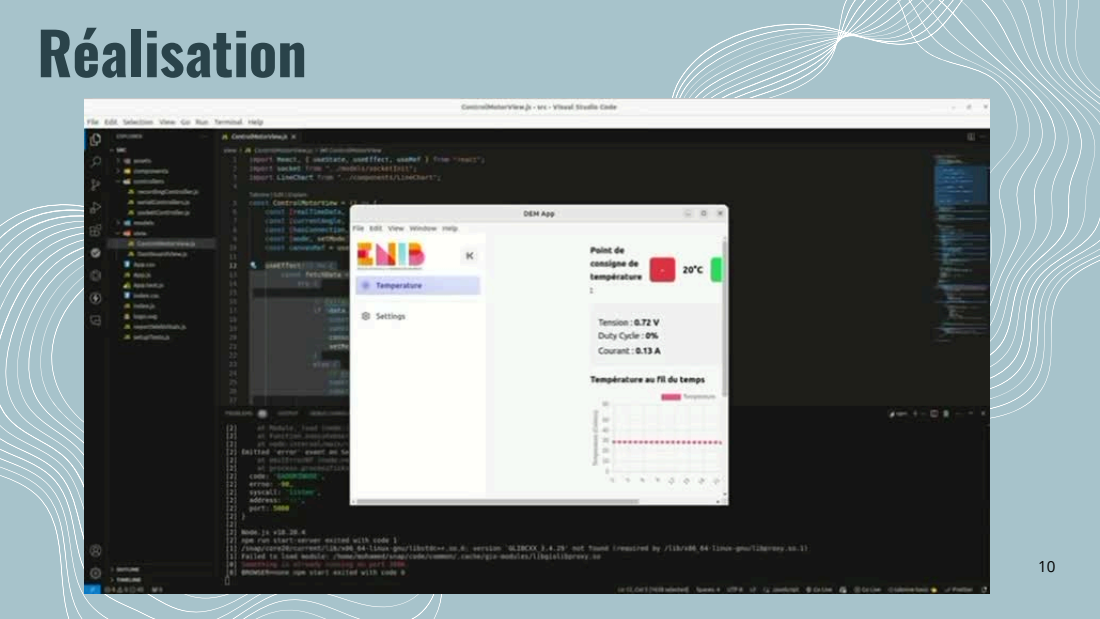
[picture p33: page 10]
Réalisation

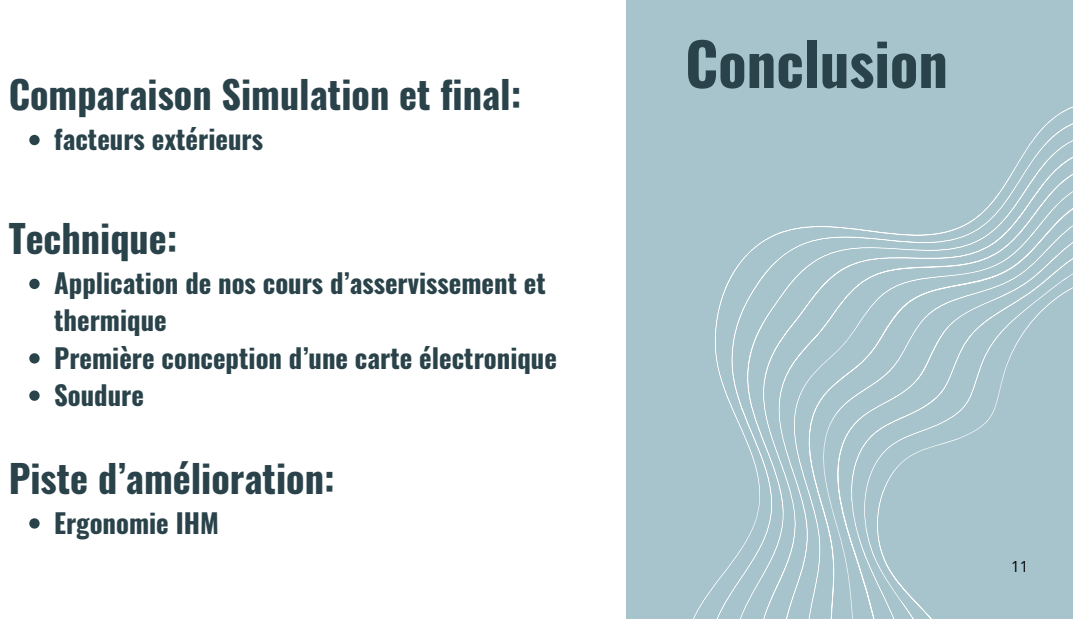
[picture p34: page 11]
Conclusion

Comparaison Simulation et final:
facteurs extérieurs
Technique:
Application de nos cours d’asservissement et
thermique
Première conception d’une carte électronique
Soudure
Piste d’amélioration:
Ergonomie IHM

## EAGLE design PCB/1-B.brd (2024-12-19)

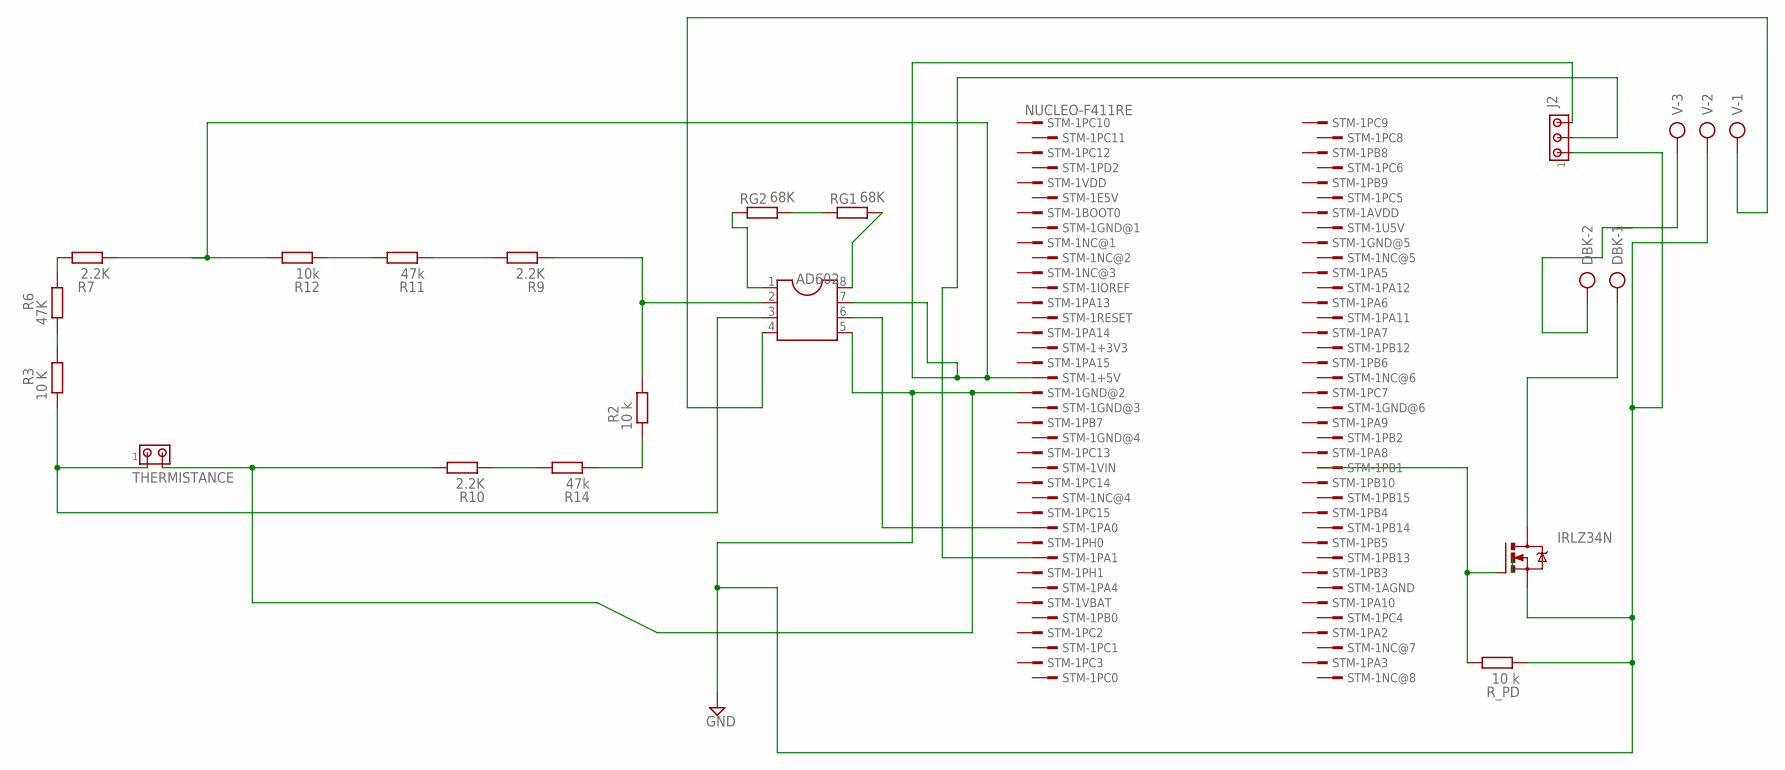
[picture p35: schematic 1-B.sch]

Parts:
AD602: DIL8; DIL08
DBK: AK500/2-H
IRLZ34N: IRLZ44Z; TO220BH
J2: MTA03-100; 10X03MTA
R2: 10 k; 0207/7
R3: 10 K; 0207/7
R6: 47K; 0207/7
R7, R9, R10: 2.2K; 0207/7
R11, R14: 47k; 0207/7
R12: 10k; 0207/7
RG1, RG2: 68K; 0207/7
R_PD: 10 k; 0207/7
STM-1: NUCLEO-F411RE; CONN_STM32_NUCLEO
THERMISTANCE: MTA02-156; 1X2MTA
V: AK500/3-H

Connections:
GND: AD602.5, IRLZ34N.S, J2.1, R10.2, R_PD.1, STM-1.19, THERMISTANCE.2, V.2
unnamed: R3.2, R6.1
unnamed: J2.2, STM-1.30
unnamed: AD602.8, RG1.2
unnamed: AD602.1, RG2.1
unnamed: IRLZ34N.G, R_PD.2, STM-1.62
unnamed: AD602.7, J2.3, R7.1, R12.2, STM-1.18
unnamed: DBK.2, V.3
unnamed: DBK.1, IRLZ34N.D
unnamed: RG1.1, RG2.2
unnamed: AD602.6, STM-1.28
unnamed: AD602.3, R3.1, THERMISTANCE.1
unnamed: AD602.4, V.1
unnamed: R6.2, R7.2
unnamed: AD602.2, R2.2, R9.1
unnamed: R9.2, R11.1
unnamed: R11.2, R12.1
unnamed: R2.1, R14.1
unnamed: R10.1, R14.2

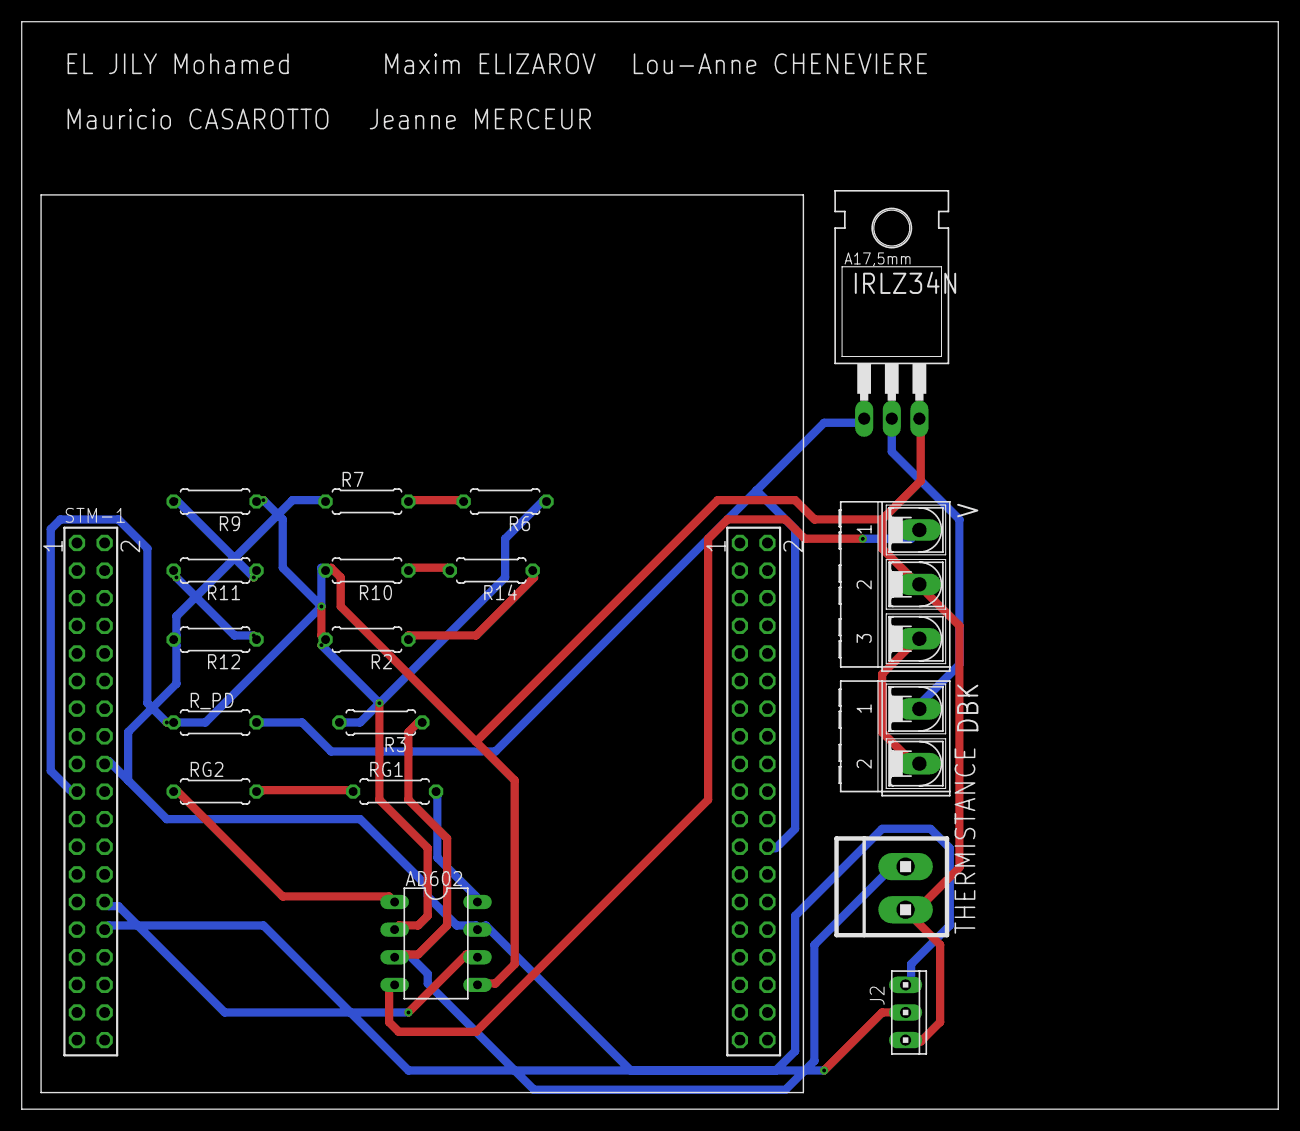
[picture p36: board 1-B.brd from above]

Board: 2 copper layers, 115.5 x 100.0 mm, 19 parts (0 on the bottom side), 19 nets.
